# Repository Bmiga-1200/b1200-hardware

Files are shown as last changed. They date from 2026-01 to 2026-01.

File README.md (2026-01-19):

# WIP

# B1200

Modern Amiga 1200 clone implementation using Cyclone V FPGA

## Features

The hardware design supports these features:

1. USB-C PD Sink / TCPC
2. USB-C DP Sink (4-lane Alt Mode)
   * DisplayPort Output
   * DisplayPort Retimer
3. USB-C 2.0 End point / Hub
   * USB Keyboard
   * USB Mouse
   * UART to FPGA Debug port
   * UART to ESP32 Programming port / bootstrap
4. KVM to switch Monitor/Keyboard/mouse between USB-C upstream or FPGA USB OTG
5. DVI-A output
   * DVI to FPGA
   * VGA to ESP32   
6. ESP32 as the embedded controller
   * KVM Switch control
   * Fan Speed Control
   * A500 Keyboard scanner
   * USB HID
   * VGA (64 color) display for boot time messages
   * RTC Emulation on I2C
   * SLiRP Modem Emulation on UART
7. FPGA I2S to analog 3.5mm audio jack output
8. DDR RAM to FPGA expansion bus
9. Cyclone V FPGA on the draughtboard

## Hardware Pin assignments:

### EC (ESP32) Functions and pin assignments

@o: output
@i: Input
3v3: +3.3V logic
1v8: +1.8V logic

* Boot strap (flash): IO0@i, EN@i, U0RXD@i3v3, U0TXD@o3v3
* TCPC
  - Negotiate SINK 5V@3A + 4-lane DP Alt Mode
* I2C Controller: IO21/SDA, IO38/SCL
* DVI-A/VGA output:
  - Red[0,1] = [IO10,IO11]@o3v3
  - Green[0,1] = [IO40,IO45]@o3v3
  - Blue[0,1] = [IO39,IO46]@o3v3
  - HSYNC = IO47@o1v8
  - VSYNC = IO48@o1v8
* DDR
  - Power Good: IO2@o3v3
  - I2C same pin as controller
* WiFi SLiRP modem, UART1
  - TxD = U1TXD@o3v3
  - RxD = U1RXD@i3v3
* KVM
  - User Switch: IO3@i falling edge
  - Port selection: IO5@o3v3, L = USBC DP, H = FPGA DP
* FPGA
  - Temp sensor interupt alaram IO4@i3v3 falling edge
  - Cooling Fan: SENS = IO7@i3v3, PWM = IO8@o3v3
  - I2C peripheral: IO41/SCL, IO42/SDA
* Expansion port:
  - ADC1_CH8
* A500 Keyboard:
  - CLK = IO12@o3v3
  - DATA = IO13@i3v3
  - RST = IO14@o3v3
  - LED STATUS = IO15@o3v3
  - LED INUSE = IO16@o3v3

### FPGA (Cyclone V) Functions and pin assignments

* DP on HDMI Flext

| Net  | FPGA Pin |
| ---- | --- |
| DP0- | AD11 |
| DP0+ | AD10 |
| DP1- | AH5 |
| DP1+ | AH6 |
| AUX- | AE7 |
| AUX+ | AF6 |
| HPD  | AF11 |

* DP on GPIO_1 header

| Net | FPGA Pin |
| --- | --- |
| DP0- | AA15 |
| DP0+ | Y15 |
| DP1- | AF28 |
| DP1+ | AF27 |
| DP2- | AH27 |
| DP2+ | AG28 |
| AUX- | AD26 |
| AUX+ | AE25 |
| HPD | AC24 |
| <span style="text-decoration:overline">LP</span> | AG26 |

* DVI-D

| Net | FPGA Pin |
| --- | --- |
| D0+ | AG25 |
| D0- | AF25 |
| D1+ | AH24 |
| D1- | AG24 |
| D2+ | AG23 |
| D2- | AF23 |
| CK+ | AH23 |
| CK- | AH22 |
| HPD | AG21 |

* SNAC on HDMI

| Pin | FPGA Pin |
| --- | --- |
| 1 | AH9 |
| 2 | AG11 |
| 3 | AF15 |
| 4 | AH11 |
| 5 | AH12 |
| 6 | AG16 |
| 7 | AF17 |
| 8 | AD4 |

* I2S for Line Out

| Net | FPGA Pin |
| --- | --- |
| DIN | AC4 |
| LRCK | AG8 |
| BCK | AG10 |
| <span style="text-decoration:overline">MUTE</span> | AH8 |

* SliRP UART

| Net | FPGA Pin |
| --- | --- |
| RXD | U9 |
| TXD | V10 |

* I2C Controller

| Net | FPGA Pin |
| --- | --- |
| SDA | AG9 |
| SCK | U14 |

* Input Switches

| Net  | FPGA Pin |
| ---- | --- |
| OSD  | AF13 |
| RST  | AG13 |
| USER | U13 |

* LED outputs

| Net | FPGA Pin |
| --- | --- |
| PWR | AA23 |
| USR | AE26 |
| DSK | Y16 |

# Thanks/Credit

Some sections of the hardware design were inspired by the following projects.

- [Terasic](https://www.terasic.com.tw/en/) DE10-Nano
- [QMTECH_Cyclone_V_SoC_KFB](https://github.com/ChinaQMTECH/QMTECH_Cyclone_V_SoC_KFB)
- [Hardware_MiSTer: Daughter boards](https://github.com/MiSTer-devel/Hardware_MiSTer) Hardware addons for MiSTer
- [PicoDVI](https://github.com/Wren6991/PicoDVI): Bitbanged DVI on the RP2040 Microcontroller
- [SNAC](https://github.com/blue212/SNAC): Accessory converter for MiSTer
- [DE10Jamma](https://github.com/MisterJamma/DE10Jamma) JAMMA interface for DE10
- [DPSwitch](https://github.com/jorticus/DPSwitch): a simple KVM-style device
- [amigakb](https://github.com/tkoecker/amigakb): Arduino Amiga keyboard interface
- [amiga-keyboard](https://github.com/hekkelek/amiga-keyboard): Mechanical Replacement Keyboard for Amiga 500 and 1200
- [Amiga1200-Plus](https://bitbucket.org/jvandezande/amiga-1200/): a re-implementation of the Amiga 1200 board
- [Amiga-Keyboard](https://github.com/solarmon/Amiga-Keyboard/): map of Commodore Amiga keyboards

# License

The hardware files in this repository are released under Creative Commons Attribution-NonCommercial-ShareAlike 4.0 International (CC BY-NC-SA 4.0)



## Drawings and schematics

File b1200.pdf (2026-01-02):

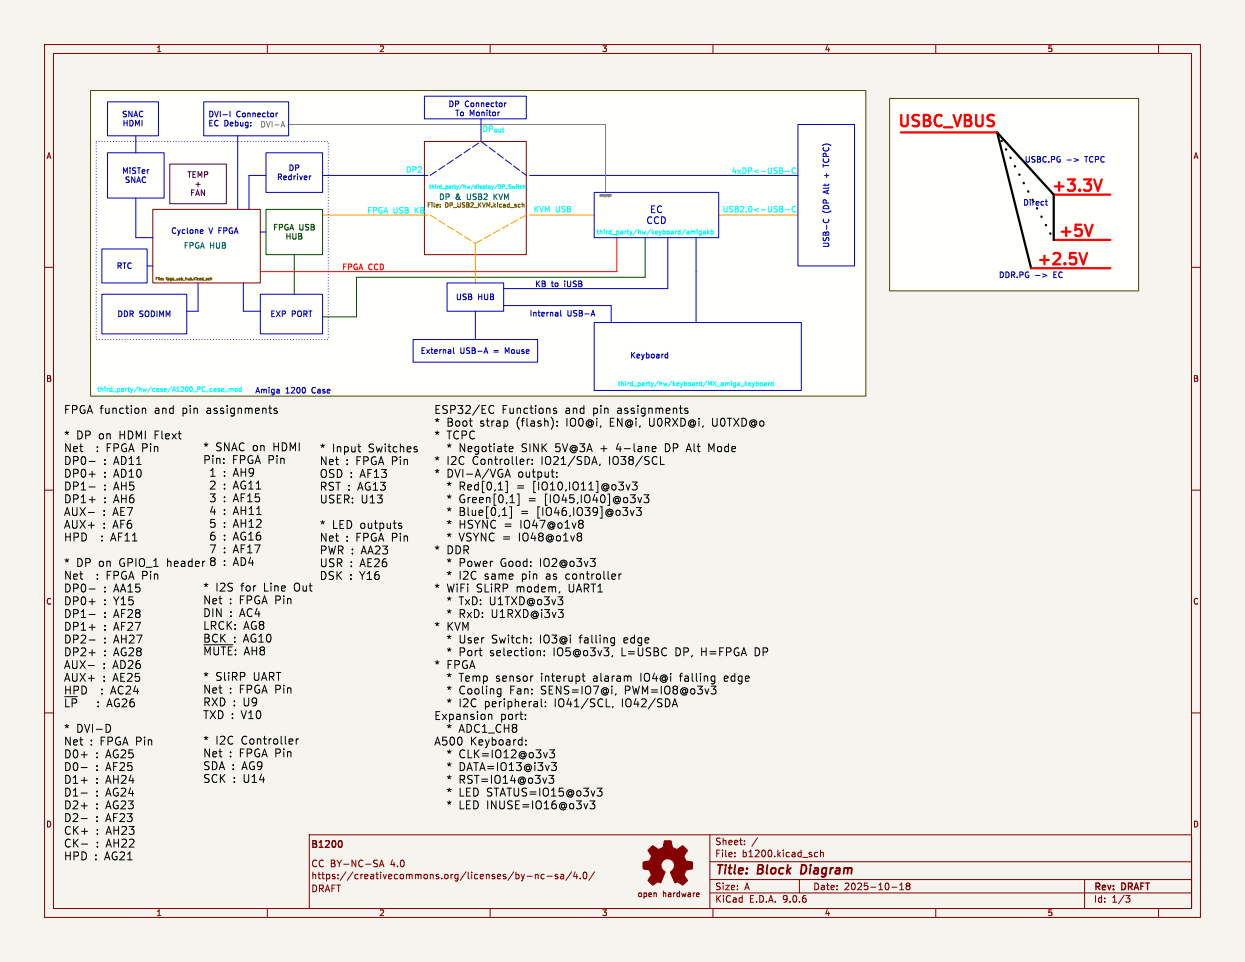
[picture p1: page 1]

third_party/hw/display/DP_Switch FPGA CCD

third_party/hw/case/A1200_PC_case_mod Cyclone V FPGA

* HSYNC = IO47@o1v8
* VSYNC = IO48@o1v8
* DDR
* Power Good: IO2@o3v3
* I2C same pin as controller * WiFi SLiRP modem, UART1

https://creativecommons.org/licenses/by-nc-sa/4.0/ DRAFT

Id: 1/3 Title: Block Diagram

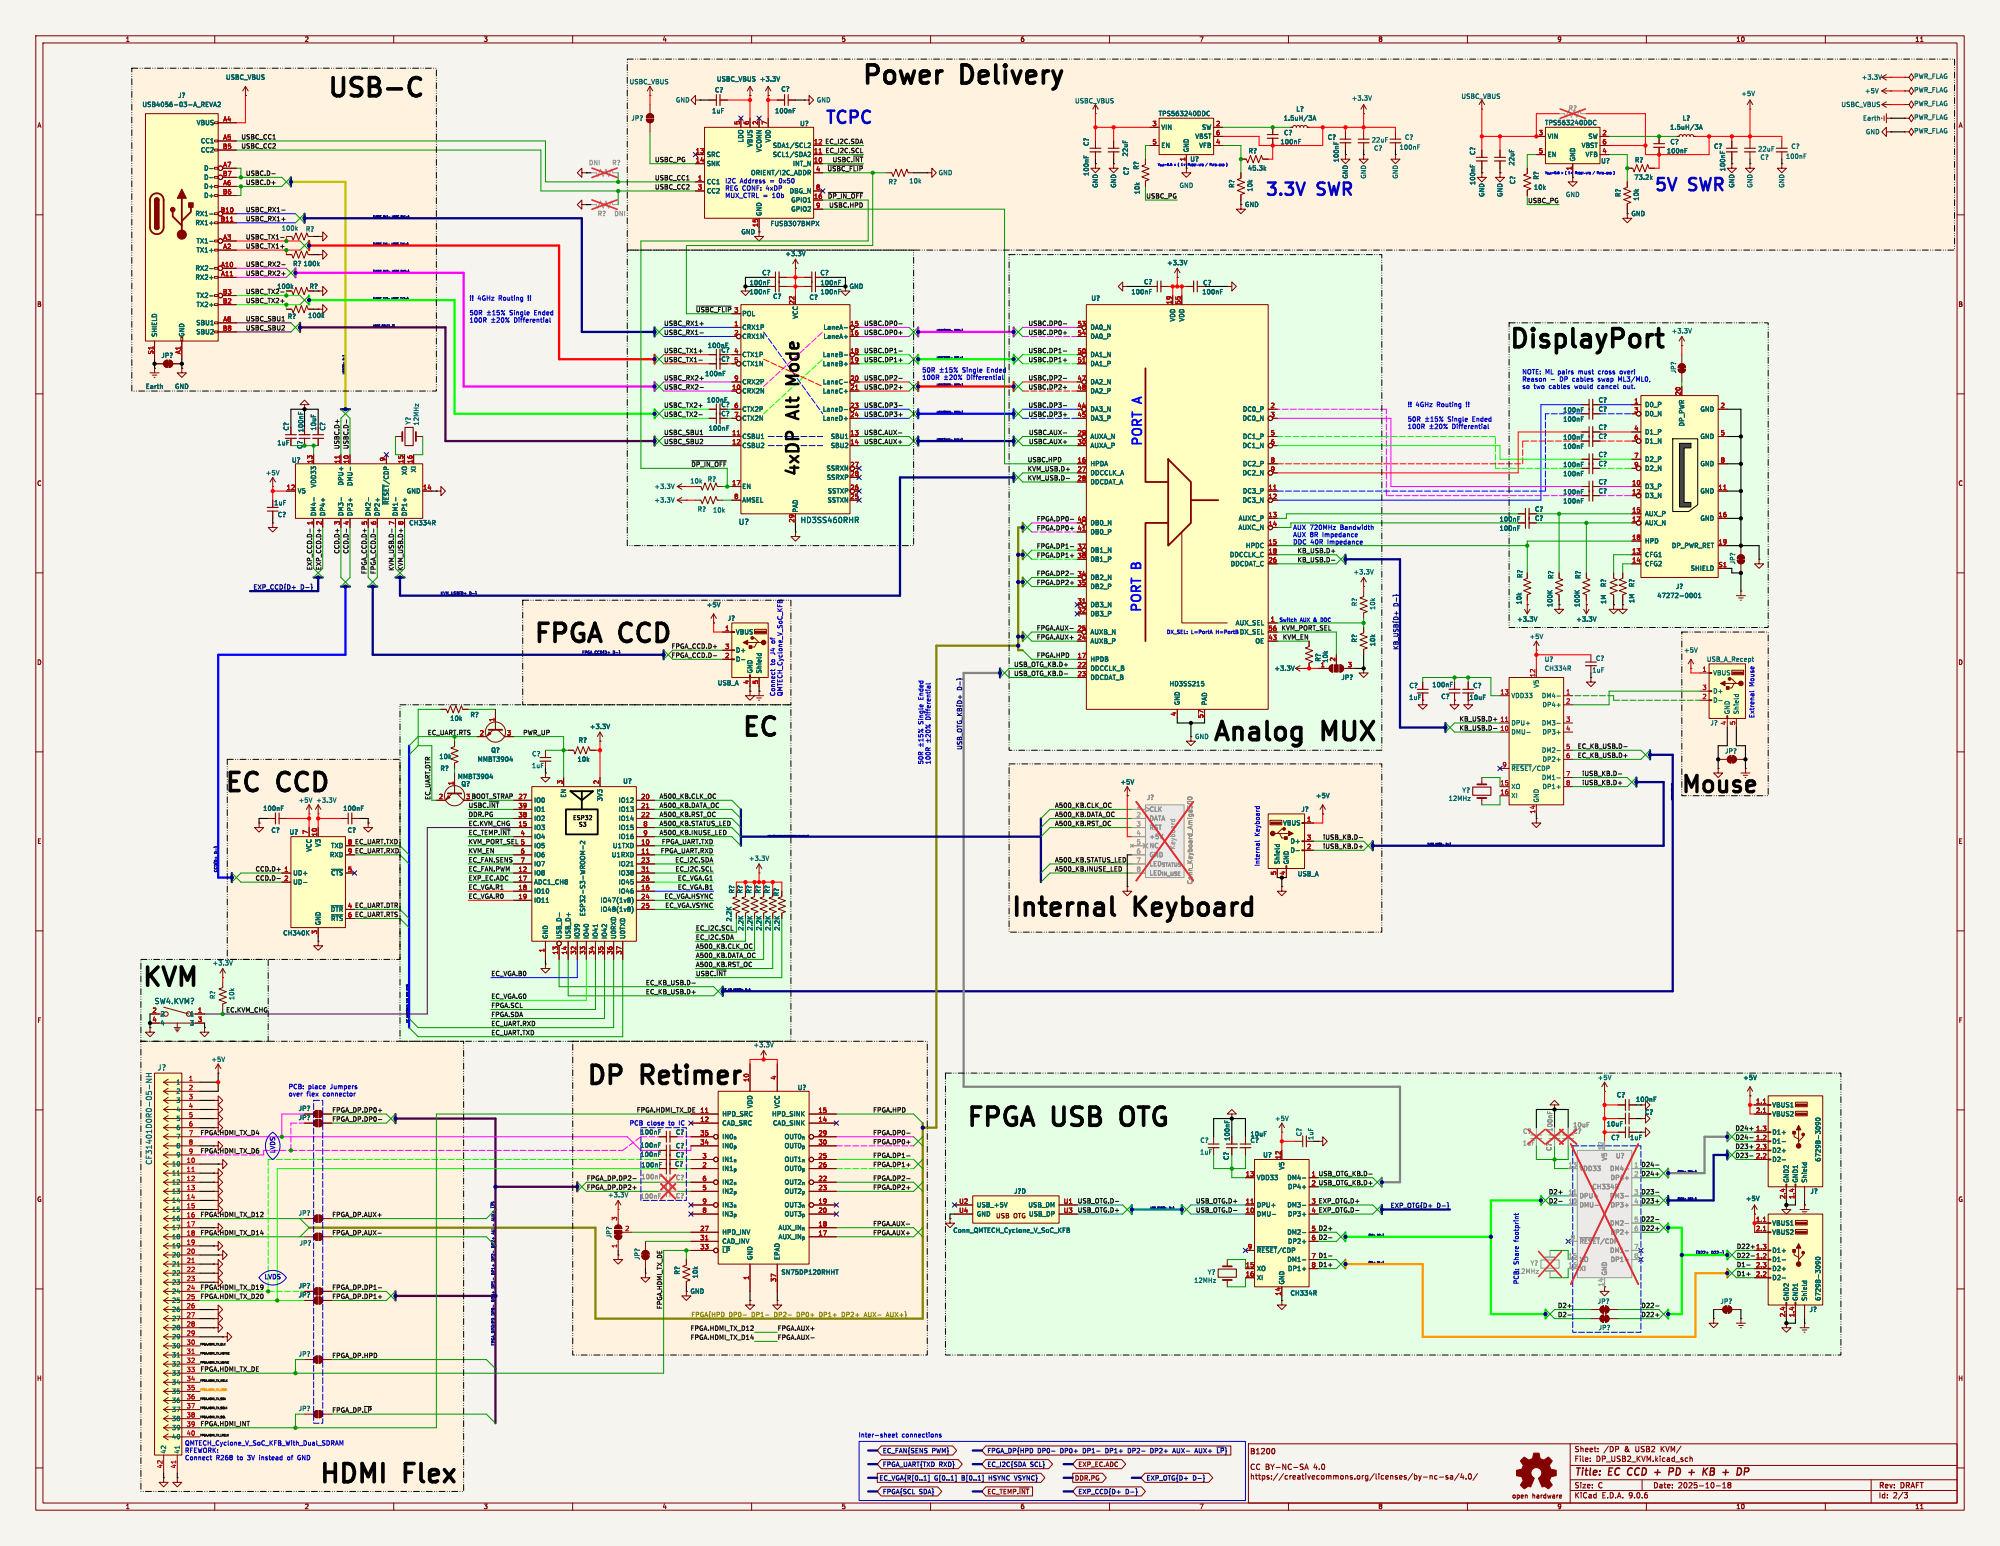
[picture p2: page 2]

Switch AUX & DDC USB-C

EC_I2C.SCL EC_I2C.SDA
I2C Address = 0x50 REG CONF: 4xDP MUX_CTRL = 10b Connect to J4 of QMTECH_Cyclone_V_SoC_KFB

V_{out}=0.6 x ( 1+ R_{VBST-VFB} / R_{VFB-GND})

USBC_PG

USBC.DP0+ FPGA.AUX+ FPGA.AUX- USBC.DP3+

!! 4GHz Routing !! 50R þÿ±15%Single Ended

3 TXD 8 RXD 9 ~{CTS}5 ~{DTR}4 ~{RTS}6 C?

3 TXD 8 RXD 9 ~{CTS}5 ~{DTR}4 ~{RTS}6 U? CH340K

FPGA.HDMI_TX_LRCLK
QMTECH_Cyclone_V_SoC_KFB_With_Dual_SDRAM
RFEWORK: Connect R268 to 3V instead of GND

FPGA_DP{HPD DP0- DP0+ DP1- DP1+ DP2- DP2+ AUX- AUX+ ~{LP}}
EC_I2C{SDA SCL}

Id: 2/3 Title: EC CCD + PD + KB + DP

https://creativecommons.org/licenses/by-nc-sa/4.0/

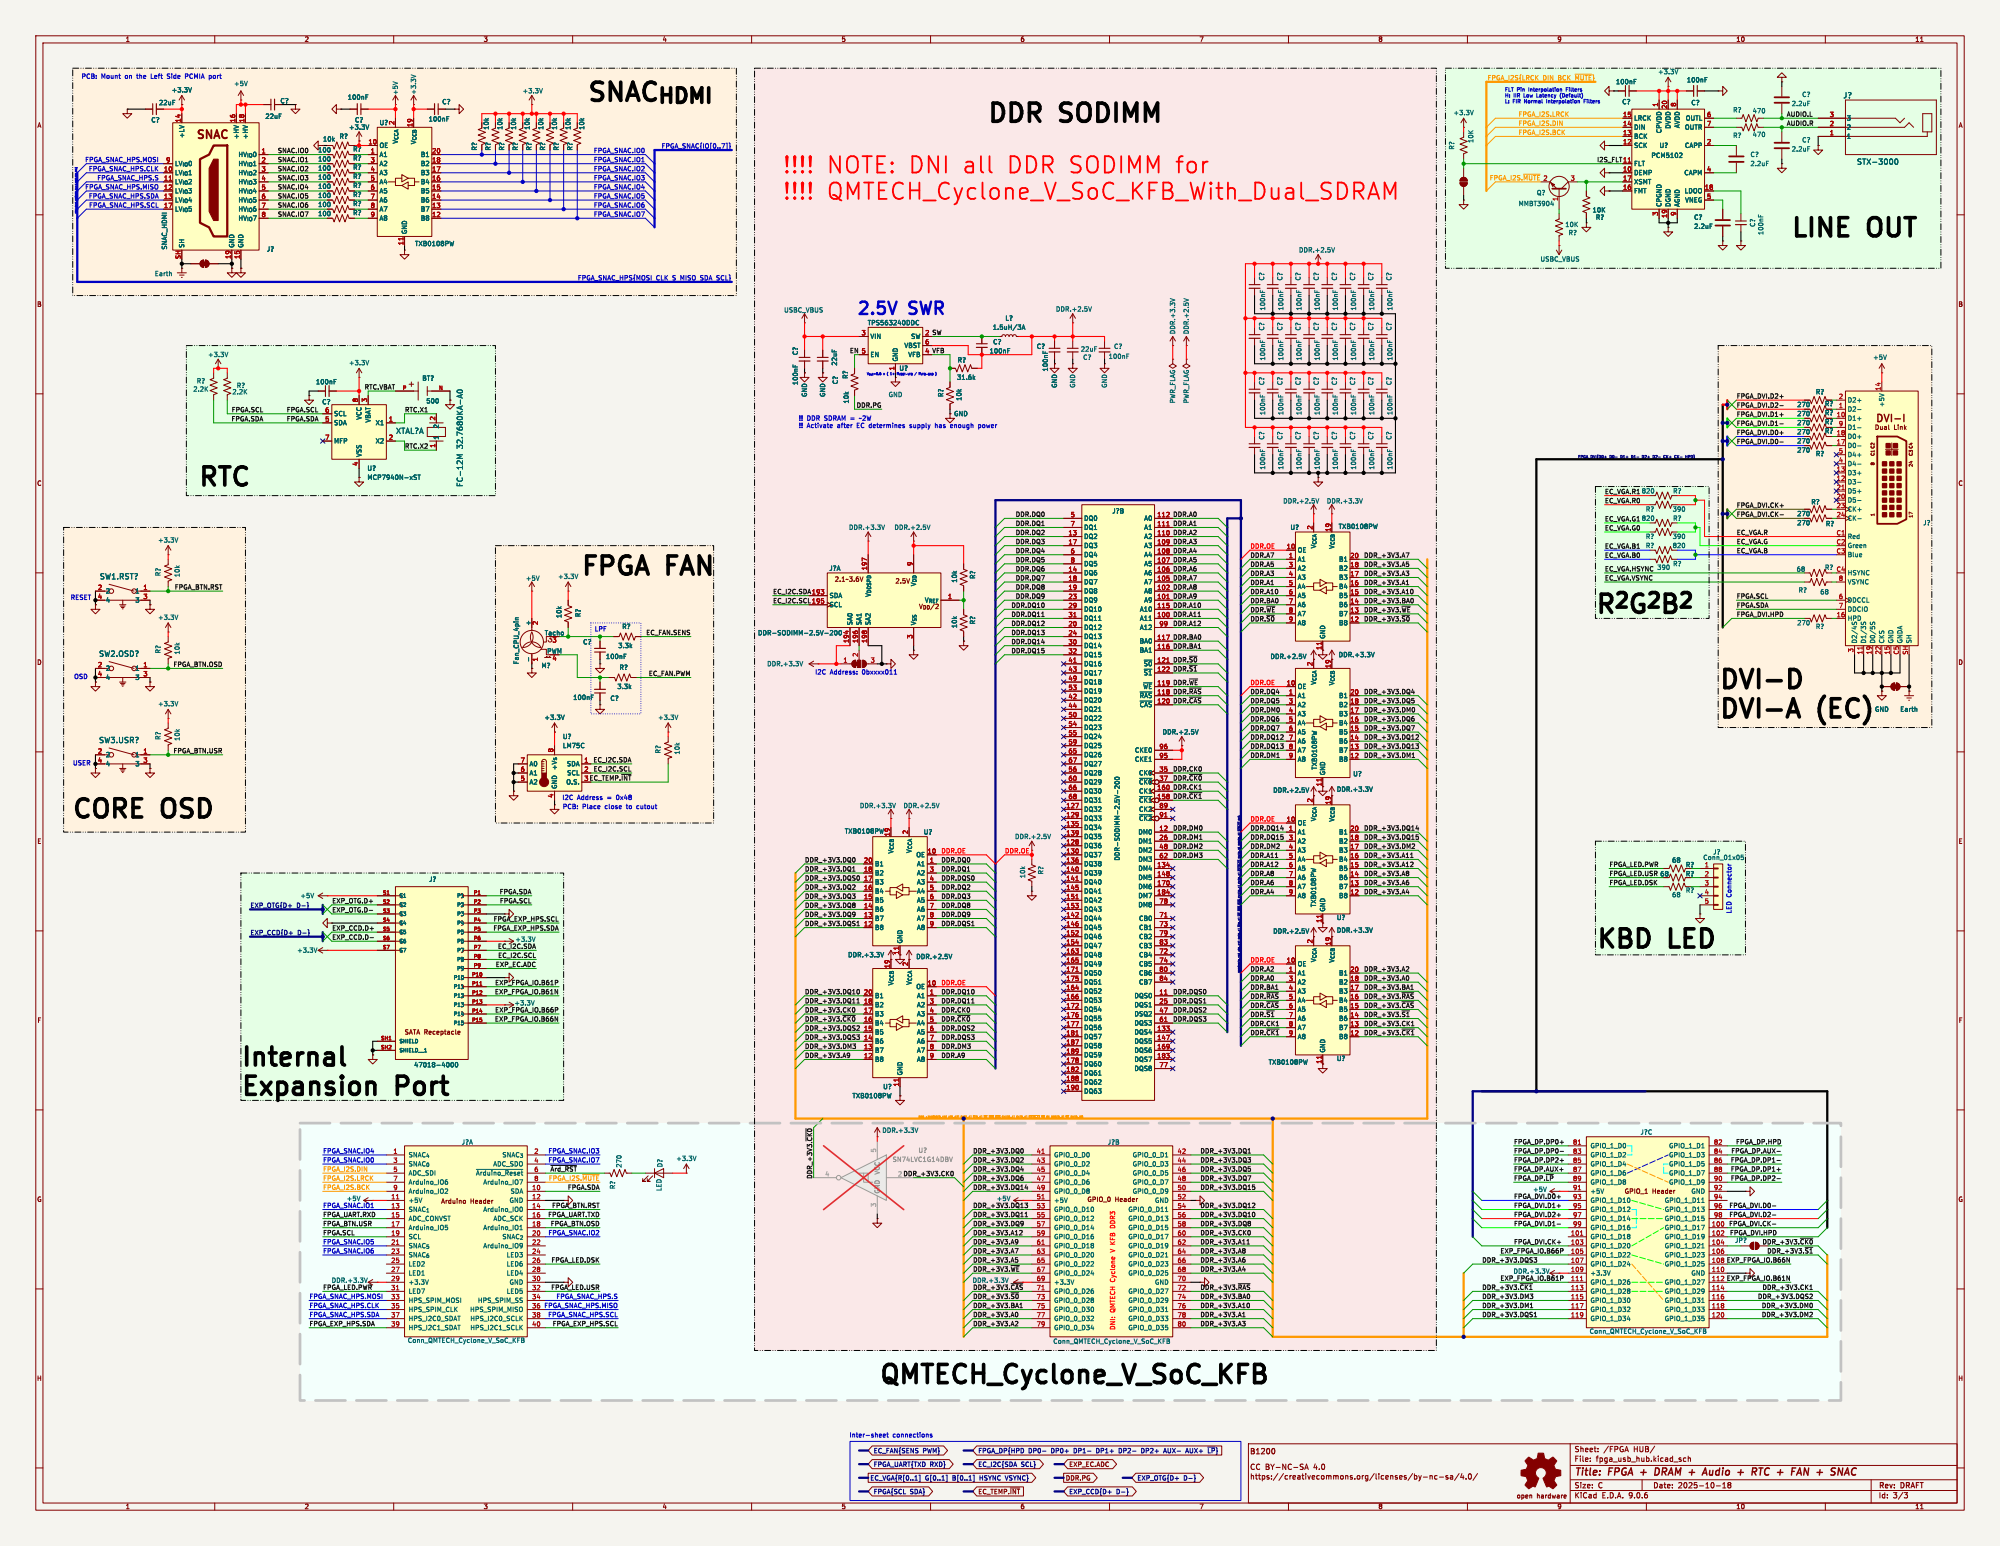
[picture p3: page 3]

PCB: Mount on the Left Side PCMIA port

FPGA_I2S{LRCK DIN BCK ~{MUTE}}

HV_{IO}01 HV_{IO}12 HV_{IO}23 HV_{IO}34 HV_{IO}45 HV_{IO}56 HV_{IO}67 HV_{IO}78 +HV 18 GND 15 +HV 16 GND 19 +LV 14 SH SH

!!!! NOTE: DNI all DDR SODIMM for
!!!! QMTECH_Cyclone_V_SoC_KFB_With_Dual_SDRAM

1 SW 2 VBST 6 VFB 4 U? TPS563240DDC C? 22uF GND GND C? 100nF DQ0 5 DQ1 7 DQ2 13 DQ3 17 DQ4 6 DQ5 8 DQ6 14 DQ7 18 DQ8 19 DQ9 23 DQ10 29 DQ11 31 DQ12 20 DQ13 24 DQ14 30 DQ15 32 DQ16 41 DQ17 43 DQ18 49 DQ19 53 DQ20 42 DQ21 44 DQ22 50 DQ23 54 DQ24 55 DQ25 59 DQ26 65 DQ27 67 DQ28 56 DQ29 60 DQ30 66 DQ31 68 DQ32 127 DQ33 129 DQ34 135 DQ35 139 DQ36 128 DQ37 130 DQ38 136 DQ39 140 DQ40 141 DQ41 145 DQ42 151 DQ43 153 DQ44 142 DQ45 146 DQ46 152 DQ47 154 DQ48 163 DQ49 165 DQ50 171 DQ51 175 DQ52 164 DQ53 166 DQ54 172 DQ55 176 DQ56 177 DQ57 181 DQ58 187 DQ59 189 DQ60 178 DQ61 182 DQ62 188 DQ63 190

1 SW 2 VBST 6 VFB 4 C? 22uF GND GND C? 100nF

!! Activate after EC determines supply has enough power QMTECH_Cyclone_V_SoC_KFB

2 U? MCP7940N-xST SCL 6 SDA 5 MFP 7 VCC

23 CK- 24 Red C1 Green C2 Blue C3 HSYNC

DDR.DQ4 DDR.DQ9 DDR.DQ7 DDR.DQ3

DDR_+3V3.~{S0} DDR_+3V3.A1 DDR.A10 DDR.BA0 DDR.A11 DDR.A12 DDR.BA0 DDR.A9 DDR.A4 DDR.A7 DDR.A5 DDR.A3 DDR.~{WE}

V_{REF}1 V_{DD}9 V_{SS} 3 V_{DDSPD} 197 SA2 198 SA1 196 SA0 194 SDA 193 SCL 195

DDR_+3V3.~{CAS} DDR_+3V3.A12 DDR_+3V3.DM2 DDR.DQS2 DDR.CK0
DDR.DQ0 DDR.OE DDR.DQ2 DDR.DQ8 DDR.DQS0 DDR.DQ3 DDR.DQ1

FPGA_DP.~{LP} FPGA_DP.AUX+ FPGA_DP.DP2+ FPGA_DP.DP0- FPGA.SCL

FPGA_DP{HPD DP0- DP0+ DP1- DP1+ DP2- DP2+ AUX- AUX+ ~{LP}} EXP_EC.ADC

Id: 3/3 Title: FPGA + DRAM + Audio + RTC + FAN + SNAC

https://creativecommons.org/licenses/by-nc-sa/4.0/

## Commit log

2025-12-11 Expand README with features and pin assignments
    Added detailed features and hardware pin assignments
2025-12-25 PDF Schematic
2025-12-29 BUG Fix: TCPC GPIO nets separated
    [DP_USB2_KVM.kicad_sch, fpga_usb_hub.kicad_sch]
2025-12-29 BUG Fix: Using TCPC SINK pin as USBC_PG to enable dead battery power-up sequence
    [DP_USB2_KVM.kicad_sch]
2025-12-29 BUG Fix: Pull Up resistor on USBC_INT_n
    [DP_USB2_KVM.kicad_sch]
2026-01-01 Cleared the annotation and regenerated PDF schematic
    [DP_USB2_KVM.kicad_sch, b1200.kicad_sch, fpga_usb_hub.kicad_sch]
2026-01-02 BUG Fix: DisplayPort HPD needs a pull b/c Monitor will pull it down when connected.
    [DP_USB2_KVM.kicad_sch]
2026-01-19 Corrected VGA pin assignements
2026-07-11 Option to power the FAN with USB-C Supply directly.
    [fpga_usb_hub.kicad_sch]
